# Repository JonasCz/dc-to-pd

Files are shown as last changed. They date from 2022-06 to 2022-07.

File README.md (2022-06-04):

# 10 - 60v input 60w DC to USB-C PD buck-boost converter module using TPS25740B and LM5118

**Status:** 

works, but **poor performance**: excessive (maybe - ?) ripple, especially in boost mode and at higher power levels. Mac laptop charges sucessfully off of it, sometimes. Diodes and inductor heats too much (80c at full load). This might be a straightforward fix, or a more siginficant design error (wrong component choice, values, or layout...)

**Why:**

The goal is that I can charge my laptop off an ebike battery directly, or any other DC source (solar system). No other solution that accepts this high input voltage in existence when I started this, now there is YZ826S from china which does the same thing (which I'll try before continueing to work on this project).

**Prototype:**

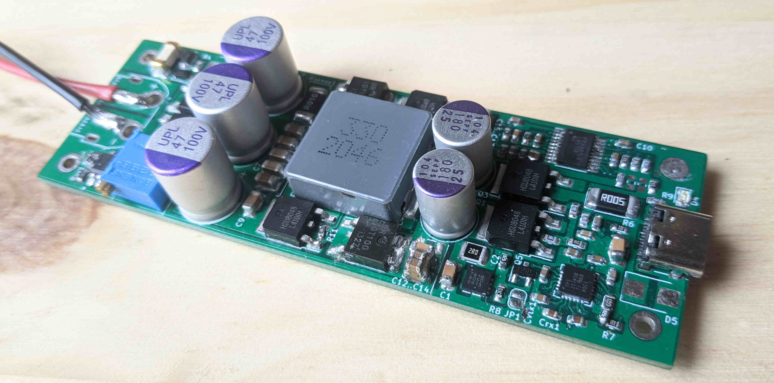
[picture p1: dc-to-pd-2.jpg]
prototype


**Features:**

* Done in Kicad 6.
* Single-sided board for easy assembly.
* The single-sidedness means that it may be possible in a future revision to replace the remaining THT parts with SMD, and then attach a heatsink or enclosure to the back, for through-the-board cooling.
* As compact as possible.
* Input protection:
     * Reverse-polarity protection provided by two high-side n-channel mosfets back-to-back, driven by HT0440.
     * Inrush current limiting provided by same mosfets, by slowing the switch-on speed significantly.
     * Fuse
     * both of these work well, I will reuse this in other designs.
* Low standby / idle power consumption: the buck-boost converter is disabled when no device (power consumer) connected.
* Adjustable low-voltage cutout.
* Datasheet implementations for TPS25740B and LM5118 are mostly folowed, only the input protection, 5v supply, and power-saving stuff has some clever stuff.
* XT60 power connectors.
* Status indicator LED.

**Warning:** 

TPS25740B seems to be discontinued with no obvious replacement. I had to buy them on Aliexpress. Has some minor bugs (I forgot what exactly. Notably needs an additional / different mosfet somewhere. I'll update this when I find my prototype board where I bodged it on. Also requires one cap around LM5118 replaced with different value).

Play with this at your own risk..

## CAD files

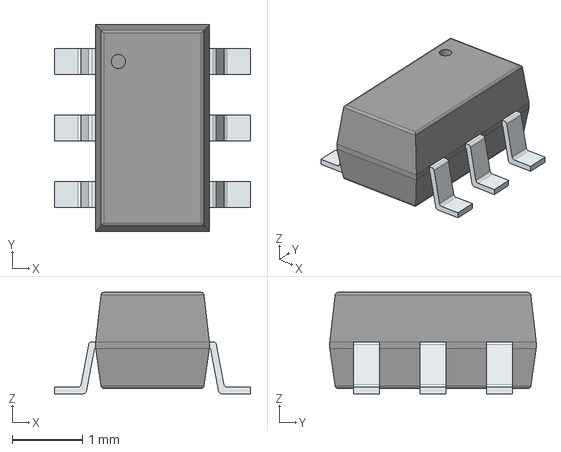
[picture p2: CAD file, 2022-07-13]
LTC1696ES6/3D/LTC1696ES6#TRMPBF.stp
2.80 x 2.95 x 1.45 mm
PinsArrayLR

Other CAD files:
LTC1696ES6/3D/LTC1696ES6#TRMPBF.stl

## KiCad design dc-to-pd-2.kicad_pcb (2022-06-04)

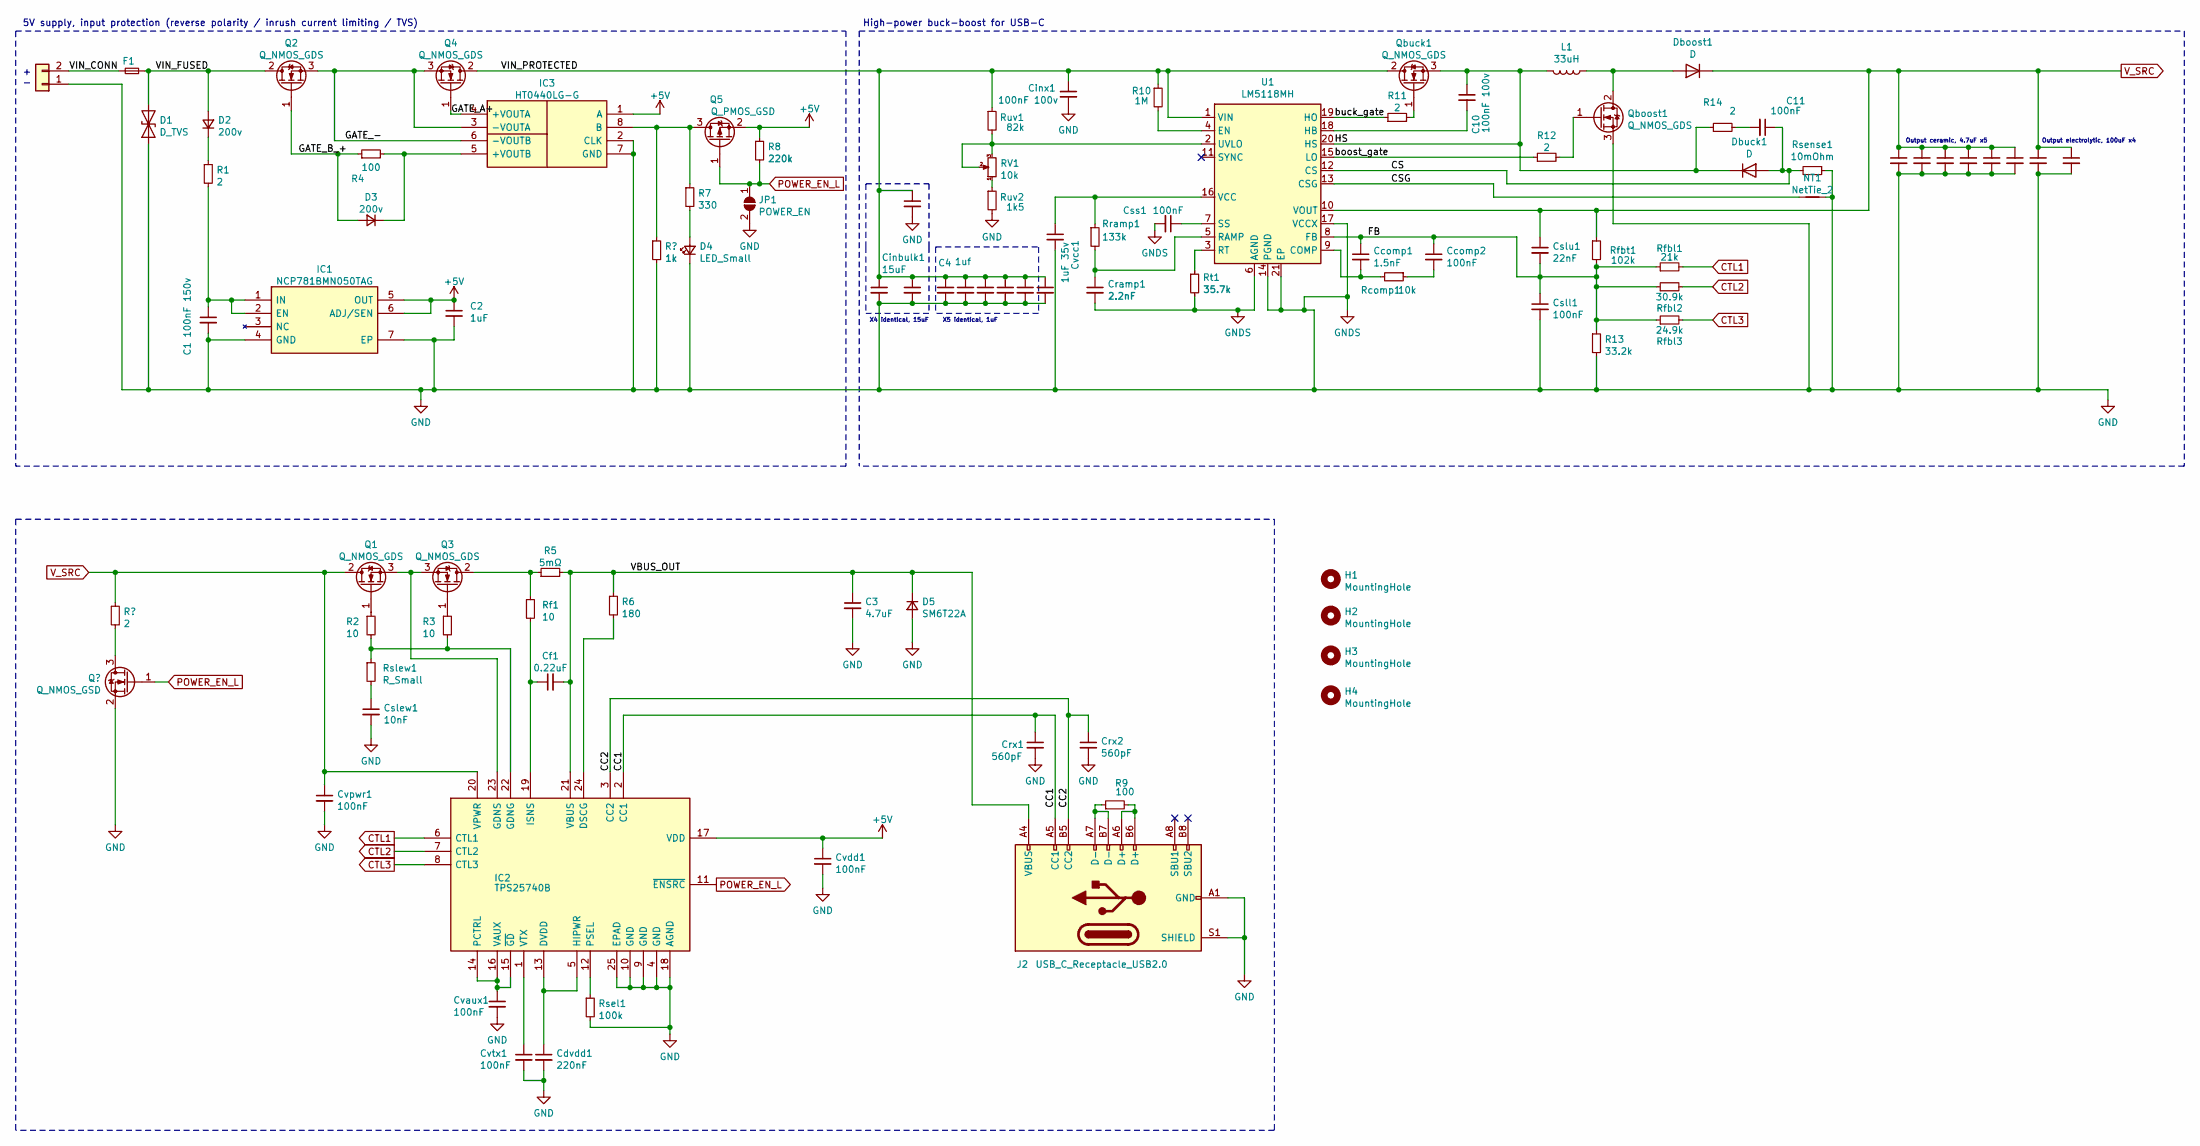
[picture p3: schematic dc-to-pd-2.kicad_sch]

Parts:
C1: 100nF 150v; C_1206_3216Metric
C2: 1uF; C_0603_1608Metric
C3, C12, C13, C14, C15, C16, C17: 4.7uF; C_1206_3216Metric; LCSC Part Number C513768
C4, C5, C6, C7, C8, C9: 1uf; C_1206_3216Metric; LCSC Part Number C840122
C10: 100nF 100v; C_0603_1608Metric; LCSC Part Number C840116
C11: 100nF; C_0603_1608Metric; LCSC Part Number C525301
Ccomp1: 1.5nF; C_0603_1608Metric; LCSC Part Number C282745
Ccomp2: 100nF; C_0603_1608Metric; LCSC Part Number C840116
Cdvdd1: 220nF; C_0603_1608Metric
Cf1: 0.22uF; C_0603_1608Metric
Cinbulk1, Cinbulk2, Cinbulk3: 15uF; CP_Radial_D10.0mm_P5.00mm; Mouser Part Number 667-80SXE27MX
Cinx1: 100nF 100v; C_0603_1608Metric; LCSC Part Number C840116
Cout1: 180uf; CP_Radial_D8.0mm_P3.50mm; Mouser Part Number 661-APSG250E181MH08S; LCSC Part Number C239314
Cout2: 180uf; CP_Radial_D8.0mm_P3.50mm; Mouser Part Number 661-APSG250E181MH08S
Cramp1: 2.2nF; C_0603_1608Metric; LCSC Part Number C376966
Crx1, Crx2: 560pF; C_0603_1608Metric
Cslew1: 10nF; C_0603_1608Metric
Csll1: 100nF; C_0603_1608Metric
Cslu1: 22nF; C_0603_1608Metric
Css1: 100nF; C_0603_1608Metric; LCSC Part Number C525301
Cvaux1: 100nF; C_0603_1608Metric
Cvcc1: 1uF 35v; C_0603_1608Metric; LCSC Part Number C28323
Cvdd1: 100nF; C_0603_1608Metric
Cvpwr1: 100nF; C_0603_1608Metric
Cvtx1: 100nF; C_0603_1608Metric
D1: D_TVS; D_SMC; LCSC Part Number C406216
D2, D3: 200v; D_SOD-123
D4: LED_Small; LED_0805_2012Metric
D5: SM6T22A; D_SMB; LCSC Part Number C283616
Dboost1: D; TO-252-2; LCSC Part Number C328574
Dbuck1: D; TO-252-2; LCSC Part Number C328574
F1: Fuse_Small; F_SMD_6.1_2.6; LCSC Part Number C182978
H1, H2, H3, H4: MountingHole; MountingHole_2.2mm_M2_DIN965_Pad
IC1: NCP781BMN050TAG; Manufacturer_Part_Number NCP781BMN050TAG; Mouser Part Number 863-NCP781BMN050TAG
IC2: TPS25740B; TI_VQFN_24_EP_2.7; Manufacturer_Part_Number TPS25740BRGER; Mouser Part Number 595-TPS25740BRGER
IC3: HT0440LG-G; SOIC-8_3.9x4.9mm_P1.27mm; Manufacturer_Part_Number HT0440LG-G; Mouser Part Number 689-HT0440LG-G
J1: Conn_01x02; Amass_XT60PW-M_Kombifootprint; LCSC Part Number C98732
J2: USB_C_Receptacle_USB2.0; USB_C_Receptacle_Palconn_UTC16-G
JP1: POWER_EN; SolderJumper-2_P1.3mm_Open_RoundedPad1.0x1.5mm
L1: 33uH; L_18x16.9_P12.5x4; LCSC Part Number C357282
NT1: NetTie_2; NetTie-2_SMD_Pad0.5mm
Q1, Q3: Q_NMOS_GDS; TO-252-2; LCSC Part Number C845608
Q2: Q_NMOS_GDS; TO-252-2; Mouser Part Number 942-IRFS4115TRLPBF
Q4: Q_NMOS_GDS; TO-252-2; Mouser Part Number 942-IRFS4115TRLPBF; LCSC Part Number C845608
Q5: Q_PMOS_GSD; SOT-23; LCSC Part Number C845585
Qboost1: Q_NMOS_GDS; TO-252-2; LCSC Part Number C845608
Qbuck1: Q_NMOS_GDS; TO-252-2; LCSC Part Number C845608
R1: 2; R_1210_3225Metric
R2, R3: 10; R_0603_1608Metric
R4, R9: 100; R_0603_1608Metric
R5: 5mΩ; R_2512_6332Metric; LCSC Part Number C457120
R6: 180; R_0603_1608Metric
R7: 330; R_0603_1608Metric
R8: 220k; R_0603_1608Metric
R10: 1M; R_0603_1608Metric; LCSC Part Number C23107
R11, R12, R14: 2; R_0603_1608Metric; LCSC Part Number C168306
R13: 33.2k; R_0603_1608Metric; LCSC Part Number C23003
RV1: 10k; Potentiometer_Bourns_3296P_Horizontal
Rcomp1: 10k; R_0603_1608Metric; LCSC Part Number C25804
Rf1: 10; R_0603_1608Metric
Rfbl1: 21k; R_0603_1608Metric; LCSC Part Number C22956
Rfbl2: 30.9k; R_0603_1608Metric; LCSC Part Number C23022
Rfbl3: 24.9k; R_0603_1608Metric; LCSC Part Number C163888
Rfbt1: 102k; R_0603_1608Metric; LCSC Part Number C170436
Rramp1: 133k; R_0603_1608Metric; LCSC Part Number C321714
Rsel1: 100k; R_0603_1608Metric
Rsense1: 10mOhm; R_2512_6332Metric; LCSC Part Number C105370
Rslew1: R_Small; R_0603_1608Metric
Rt1: 35.7k; R_0603_1608Metric; LCSC Part Number C23091
Ruv1: 82k; R_0603_1608Metric; LCSC Part Number C23107
Ruv2: 1k5; R_0603_1608Metric; LCSC Part Number C23107
U1: LM5118MH; Texas_PWP0020A; LCSC Part Number C55878

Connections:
+5V: C2.1, Cvdd1.1, IC1.5 (OUT), IC1.6 (ADJ/SEN), IC2.17 (VDD), IC3.1 (A), Q5.2 (S), R8.1
/CC1: Crx1.1, IC2.2 (CC1), J2.A5 (CC1)
/CC2: Crx2.1, IC2.3 (CC2), J2.B5 (CC2)
/CS: C11.1, Dbuck1.2 (A), Rsense1.2, U1.12 (CS)
/CSG: NT1.1, U1.13 (CSG)
/FB: Ccomp1.1, Ccomp2.1, Csll1.1, Cslu1.2, R13.1, Rfbl1.1, Rfbl2.1, Rfbl3.1, Rfbt1.2, U1.8 (FB)
/GATE_-: IC3.3 (-VOUTA), IC3.6 (-VOUTB), Q2.3 (S), Q4.3 (S)
/GATE_A+: IC3.4 (+VOUTA), Q4.1 (G)
/GATE_B_+: D3.2 (A), Q2.1 (G), R4.1
/HS: C10.1, Dbuck1.1 (K), L1.2, Qbuck1.3 (S), R14.1, U1.20 (HS)
/VBUS_OUT: C3.1, Cf1.2, D5.1 (K), IC2.21 (VBUS), J2.A4 (VBUS), J2.A9 (VBUS), J2.B4 (VBUS), J2.B9 (VBUS), R5.2, R6.1
/VIN_CONN: F1.2, J1.2
/VIN_FUSED: D1.2 (A2), D2.2 (A), F1.1, Q2.2 (D)
/VIN_PROTECTED: C4.1, C5.1, C6.1, C7.1, C8.1, C9.1, Cinbulk1.1, Cinbulk2.1, Cinbulk3.1, Cinx1.1, Q4.2 (D), Qbuck1.2 (D), R10.1, Ruv1.1, U1.1 (VIN)
/boost_gate: R12.1, U1.15 (LO)
/buck_gate: R11.1, U1.19 (HO)
CTL1: IC2.6 (CTL1), Rfbl1.2
CTL2: IC2.7 (CTL2), Rfbl2.2
CTL3: IC2.8 (CTL3), Rfbl3.2
GND: C1.2, C2.2, C3.2, C4.2, C5.2, C6.2, C7.2, C8.2, C9.2, C12.2, C13.2, C14.2, C15.2, C16.2, C17.2, Cdvdd1.2, Cinbulk1.2, Cinbulk2.2, Cinbulk3.2, Cinx1.2, Cout1.2, Cout2.2, Cramp1.2, Crx1.2, Crx2.2, Cslew1.2, Csll1.2, Css1.2, Cvaux1.2, Cvcc1.2, Cvdd1.2, Cvpwr1.2, Cvtx1.2, D1.1 (A1), D4.1 (K), D5.2 (A), H1.1, IC1.4 (GND), IC1.7 (EP), IC2.4 (GND), IC2.9 (GND), IC2.10 (GND), IC2.18 (AGND), IC2.25 (EPAD), IC3.2 (CLK), IC3.7 (GND), J1.1, J2.A1 (GND), J2.A12 (GND), J2.B1 (GND), J2.B12 (GND), J2.S1 (SHIELD), JP1.2 (B), NT1.2, Qboost1.3 (S), R13.2, Rsel1.2, Rsense1.1, Rt1.2, Ruv2.2, U1.6 (AGND), U1.14 (PGND), U1.17 (VCCX), U1.21 (EP)
unnamed: C1.1, IC1.1 (IN), IC1.2 (EN), R1.2
unnamed: C10.2, U1.18 (HB)
unnamed: C11.2, R14.2
unnamed: Ccomp1.2, Rcomp1.2, U1.9 (COMP)
unnamed: Ccomp2.2, Rcomp1.1
unnamed: Cdvdd1.1, IC2.5 (HIPWR), IC2.13 (DVDD)
unnamed: Cf1.1, IC2.19 (ISNS), Rf1.2
unnamed: Cramp1.1, Rramp1.2, U1.5 (RAMP)
unnamed: Cslew1.1, Rslew1.2
unnamed: Css1.1, U1.7 (SS)
unnamed: Cvaux1.1, IC2.14 (PCTRL), IC2.15 (~GD), IC2.16 (VAUX)
unnamed: Cvcc1.1, Rramp1.1, U1.16 (VCC)
unnamed: Cvtx1.1, IC2.1 (VTX)
unnamed: D2.1 (K), R1.1
unnamed: D3.1 (K), IC3.5 (+VOUTB), R4.2
unnamed: D4.2 (A), R7.2
unnamed: Dboost1.2 (A), L1.1, Qboost1.2 (D)
unnamed: IC2.12 (PSEL), Rsel1.1
unnamed: IC2.22 (GDNG), R2.2, R3.2, Rslew1.1
unnamed: IC2.23 (GDNS), Q1.3 (S), Q3.3 (S)
unnamed: IC2.24 (DSCG), R6.2
unnamed: IC3.8 (B), Q5.3 (D), R7.1
unnamed: J2.A6 (D+), J2.B6 (D+), R9.2
unnamed: J2.A7 (D-), J2.B7 (D-), R9.1
unnamed: Q1.1 (G), R2.1
unnamed: Q3.1 (G), R3.1
unnamed: Q3.2 (D), R5.1, Rf1.1
unnamed: Qboost1.1 (G), R12.2
unnamed: Qbuck1.1 (G), R11.2
unnamed: R10.2, U1.4 (EN)
unnamed: RV1.1, Ruv2.1
unnamed: RV1.2, RV1.3, Ruv1.2, U1.2 (UVLO)
unnamed: Rt1.1, U1.3 (RT)
POWER_EN_L: IC2.11 (~ENSRC), JP1.1 (A), Q5.1 (G), R8.2
V_SRC: C12.1, C13.1, C14.1, C15.1, C16.1, C17.1, Cout1.1, Cout2.1, Cslu1.1, Cvpwr1.1, Dboost1.1 (K), IC2.20 (VPWR), Q1.2 (D), Rfbt1.1, U1.10 (VOUT)

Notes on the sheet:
5V supply, input protection (reverse polarity / inrush current limiting / TVS)
+ -
High-power buck-boost for USB-C
X4 identical, 15uF
X5 identical, 1uF
Output ceramic, 4.7uF x5
Output electrolytic, 100uF x4

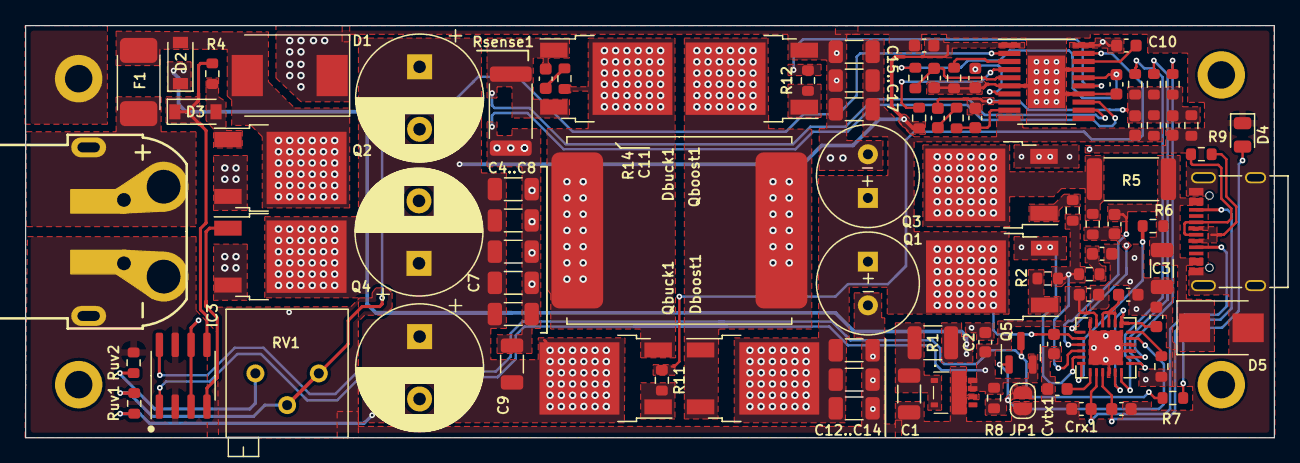
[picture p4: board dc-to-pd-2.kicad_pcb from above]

Board: 4 copper layers, 100.0 x 33.0 mm, 95 parts (1 on the bottom side), 55 nets.
